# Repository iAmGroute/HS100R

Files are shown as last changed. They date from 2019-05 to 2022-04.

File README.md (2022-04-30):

# HS100R  
  
A custom pcb for the [TP-Link HS100 and HS110](https://www.tp-link.com/en/home-networking/smart-plug/hs110/) smart plugs.  
  
### Features:  
  
  - Uses the low power nRF51 SoC (+4dBm 2.4GHz) instead of a WiFi module.  
    Compatible with the popular nRF24 series modules.  
  
  - Maintains the features of the original HS100.  
  
  - Added sensors:  
  
Sensor      | MPN  
------------|-----  
Light       | LTR-30XALS  
Pressure    | DPS310  
Humidity    | SI7006-A20  
Temperature | SI7006-A20  
  
  - Adds low frequency front end for mains Voltage and Current sensing, wired to the ADC of the nRF51:  
    The idea is to function as a very basic oscilloscope.  
    Full bandwidth: 10 KHz  
      A gpio is wired to a low-pass filter at the input of the ADC, so that the bandwidth can be limited to around 1 KHz on demand.  
    Sampling frequency: around 40K samples/s (at 8 bits; around 20K samples/s at 10 bits)  
    For the current sensing side, a shunt resistor is required at the relay's board  
    (already installed on the HS110 - 1 mOhm, but will require cutting the board on the HS100 - 4 mOhm recommended)  
    Two low noise PGAs (MAX9939) are added in series to give a high dynamic range.  
    Max gain is limitted by the first PGA's noise at around 3000x (measures a few tens of mA with 4 mOhm shunt)  
  
  - The above can also be used to do Point-on-Wave switching:  
    Turn the relay on when the instantaneous voltage is near zero  
    and turn it off when the instantaneous current is near zero.  
    This is done to prevend arcing on the contacts of the relay and greately improve its life span  
    especially when switching heavy loads.  
  
### Prototype images and screenshots:  
  
#### Photos of the whole unit:
External photo 1 | External photo 2
-----------------|------------------
 | 
  
#### Custom PCB:
Top side | Bottom side
---------|-------------
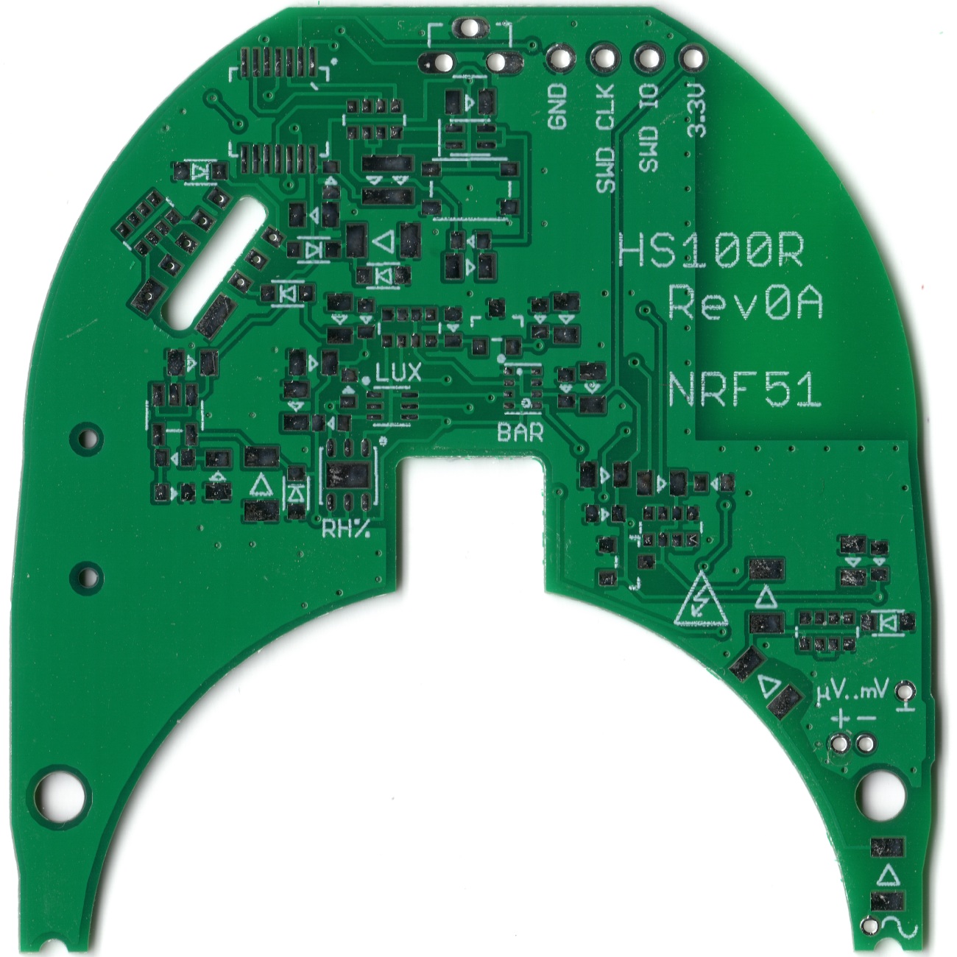
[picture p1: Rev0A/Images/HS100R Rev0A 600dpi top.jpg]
PCB top side
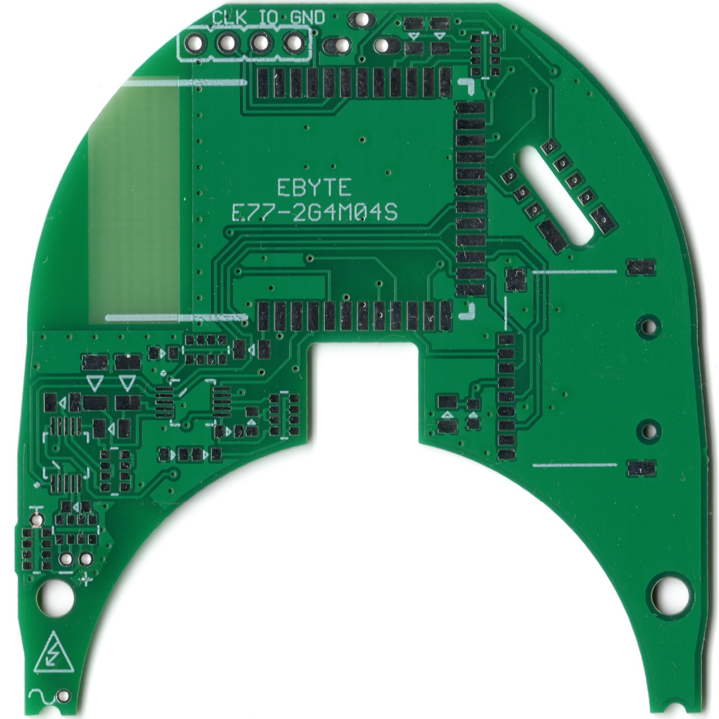
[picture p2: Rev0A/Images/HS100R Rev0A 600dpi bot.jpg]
PCB bottom side
 | 

#### Oscilloscope function screenshot ([Processing](https://en.wikipedia.org/wiki/Processing_(programming_language)) app):
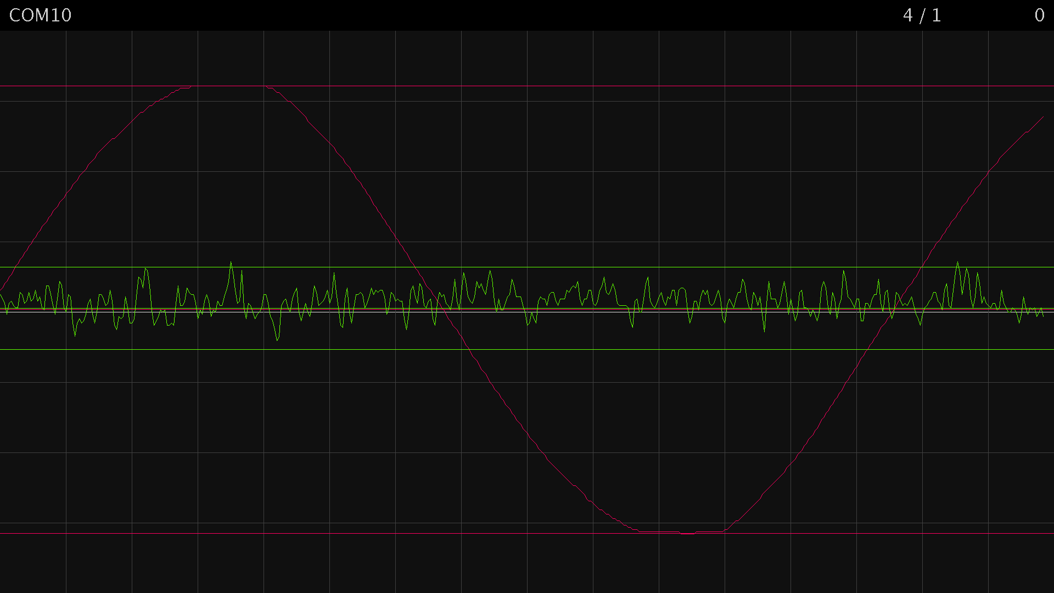
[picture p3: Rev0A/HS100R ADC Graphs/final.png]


### Note about revisions:  
  
Revisions that begin with 0 (e.g. Rev0B) are prototypes and only for reference and development.  
Unfortunately, TP-Link has discontinued these smart-plugs (at least in Europe), so development on this project has stopped.

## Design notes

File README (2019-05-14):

# HS100R

A custom pcb for the TP-Link HS100 and HS110 smart plugs.

### Features:

  - Uses the low power nRF51 SoC (+4dBm 2.4GHz) instead of a WiFi module.
    Compatible with the popular nRF24 series modules.

  - Maintains the features of the original HS100.

  - Added sensors:

Sensor      | MPN
------------|-----
Light       | LTR-30XALS
Pressure    | DPS310
Humidity    | SI7006-A20
Temperature | SI7006-A20

  - Adds low frequency front end for mains Voltage and Current sensing, wired to the ADC of the nRF51:
    The idea is to function as a very basic oscilloscope.
    Full bandwidth: 10 KHz
      A gpio is wired to a capacitor at the input of the ADC, so that the bandwidth can be limited to around 1 KHz on demand.
    Sampling frequency: around 40 KSps (at 8 bits, around half at 10 bits)
    For the current sensing side, a current shunt resistor is required at the relay's board
    (already installed on the HS110 - 1 mOhm, will require cutting the board on the HS100 - 4 mOhm recommended)
    Two low noise PGAs (MAX9939) are added in series to give a high dynamic range.
    Max gain limitted by the front PGA's noise at around 3000x (measures a few tens of mA with 4 mOhm shunt)

  - The above can also be used to do Point-on-Wave switching:
    Turn the relay on when the instantaneous voltage is near zero
    and turn it off when the instantaneous current is near zero.
    This is done to prevend arcing on the contacts of the relay and greately improve its life span
    especially when switching heavy loads.

### Prototype pictures and screenshots:

Comming soon !

### Note about revisions:

Revisions that begin with 0 (e.g. Rev0B) are prototypes and only for reference and development.
No fully working design is available yet.

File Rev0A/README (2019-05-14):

# HS100R Rev0A

Status: Finished (Archived)

## Known issues:

  - The pins of the pressure sensor (DPS310) are in the wrong order, so the sensor should not be mounted.
    [Datasheet, page 5](https://www.infineon.com/dgdl/Infineon-DPS310-DS-v01_00-EN.pdf?fileId=5546d462576f34750157750826c42242)
    (Note: the numbering is confusing, it starts from top right instead of top left)

  - The RF module's performance needs to be tested after being soldered on the pcb, and later placed in the case.
    It is possible that the FR4 below the antenna interferes.

  - It is not possible to fit the SD card without modifications to the case.

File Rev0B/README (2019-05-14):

# HS100R Rev0B

Status: Unfinished

TODO:

  - Remove SD card slot, or reposition it.

  - Fix the area of the DPS310. (maybe switch to a different IC ?)

  - Reevaluate the ground layer around the DPS310.

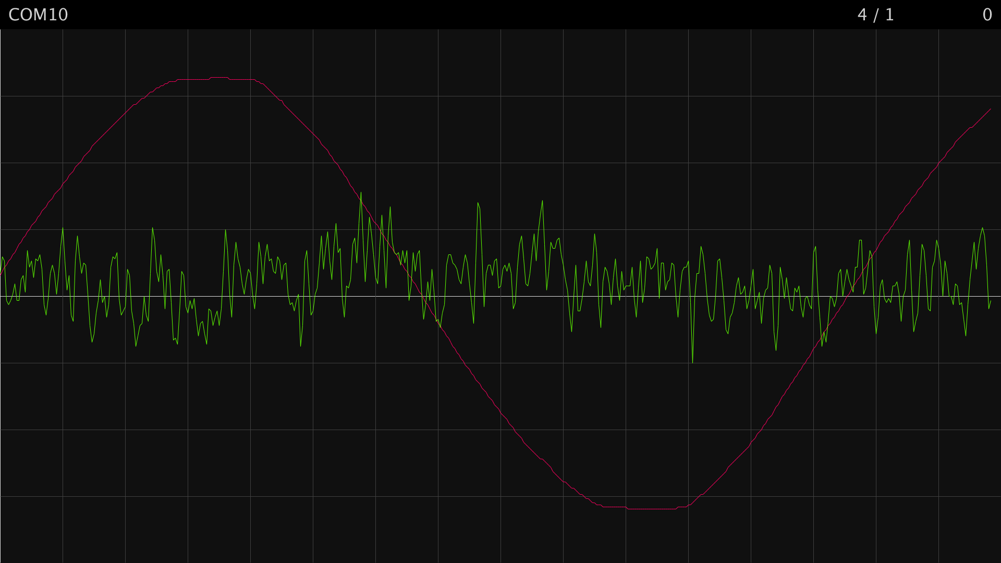
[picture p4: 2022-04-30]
Rev0A/HS100R ADC Graphs/no trim max gain 8 bit 1.png

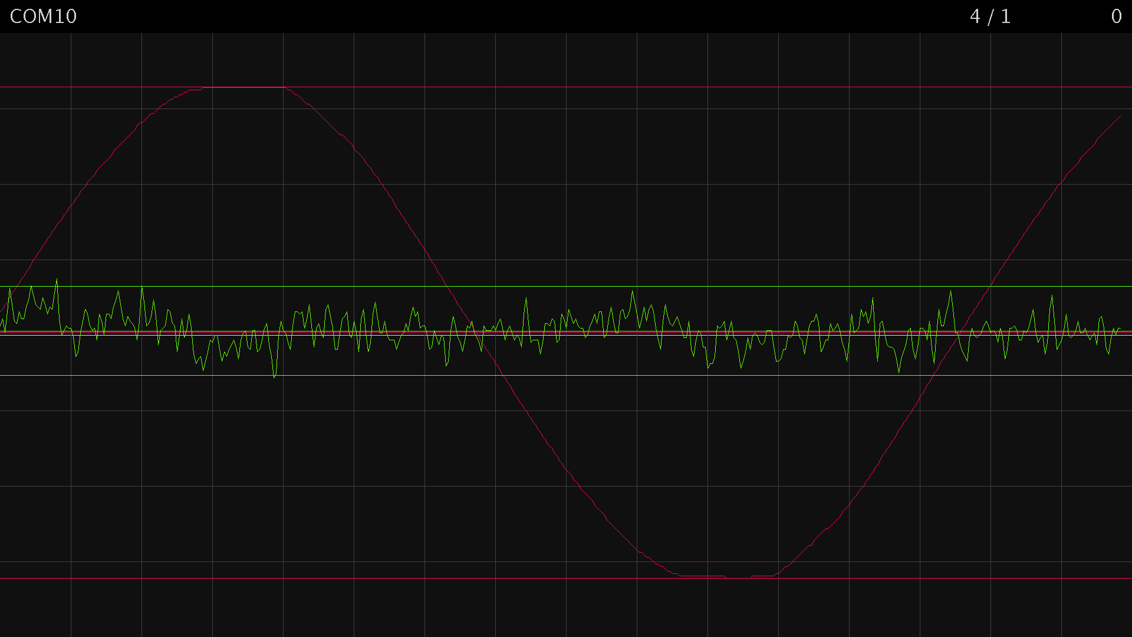
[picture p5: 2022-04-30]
Rev0A/HS100R ADC Graphs/cap and res.png

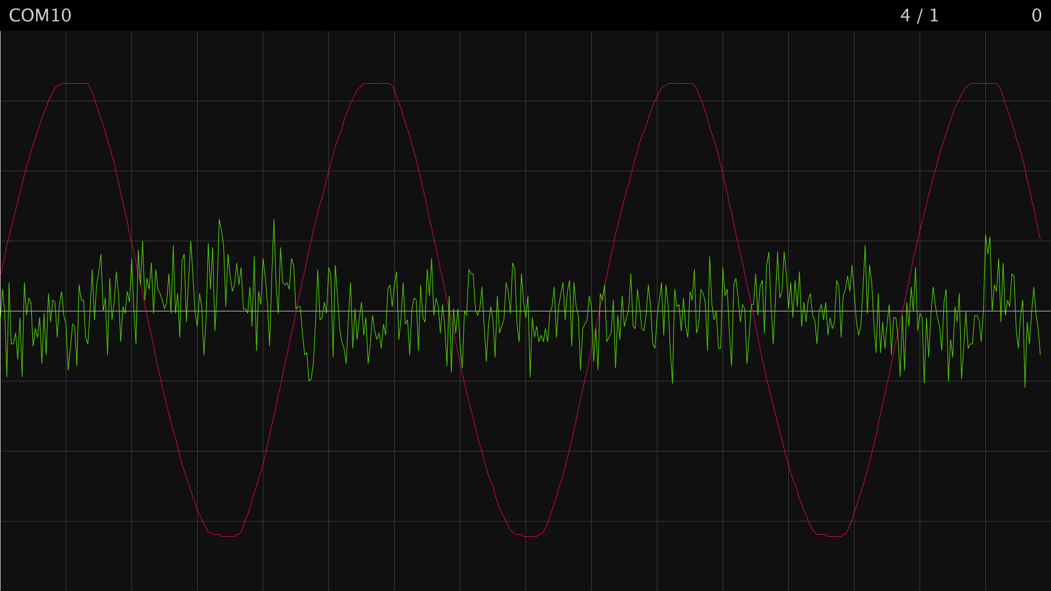
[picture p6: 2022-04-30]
Rev0A/HS100R ADC Graphs/no trim max gain 10 bit 2.png

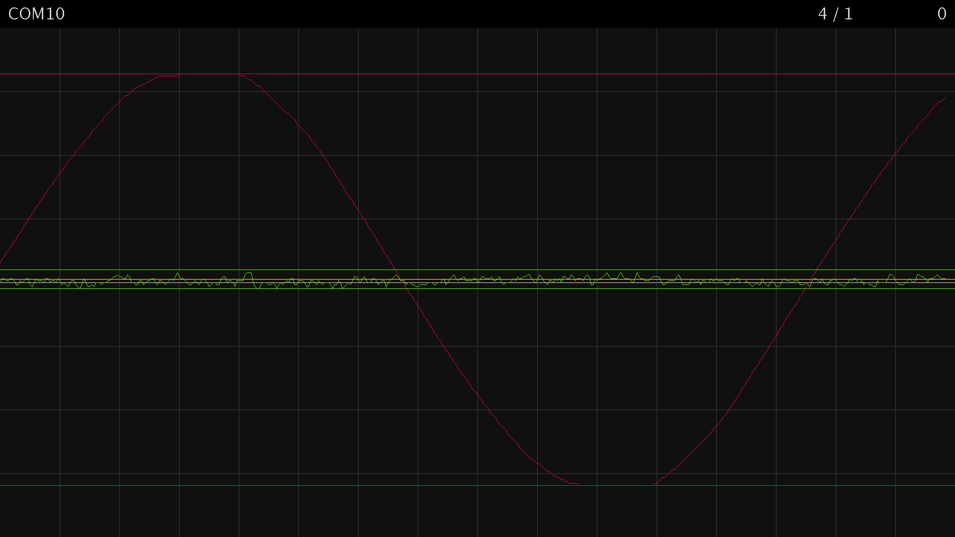
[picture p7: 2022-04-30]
Rev0A/HS100R ADC Graphs/cap no res 2.png

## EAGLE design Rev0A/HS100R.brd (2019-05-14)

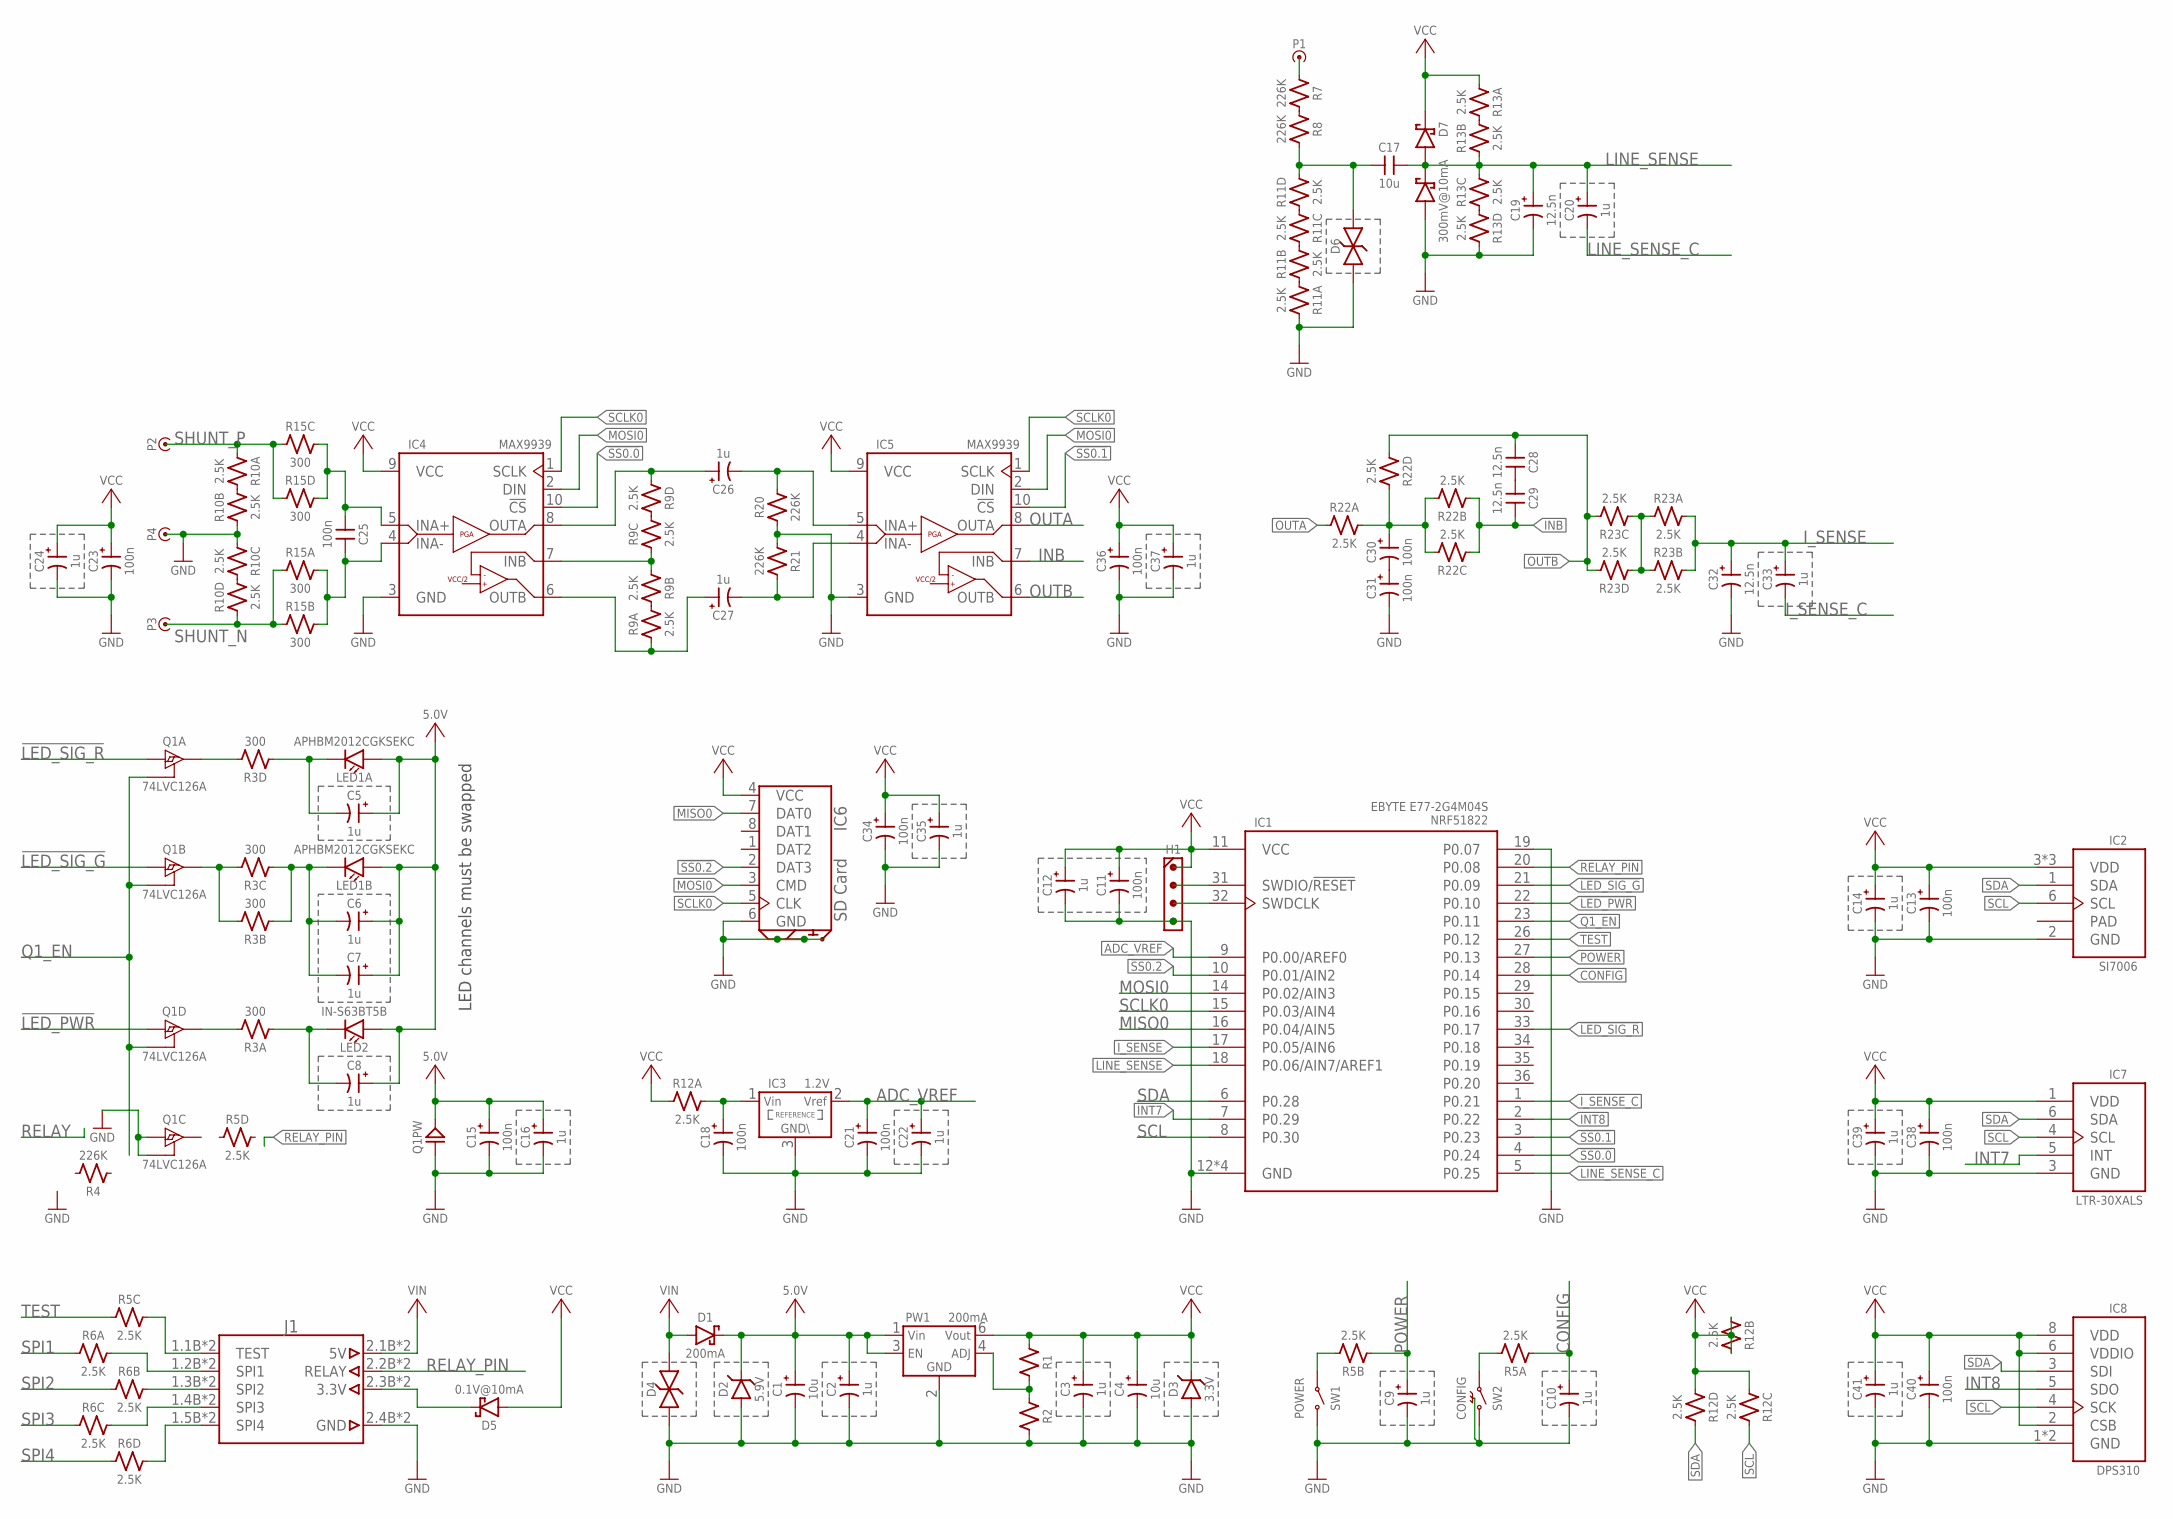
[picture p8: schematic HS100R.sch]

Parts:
C1, C4, C17: 10u; 1206
C2, C3, C5, C6, C7, C8, C9, C10, C12, C14, C16, C20, C22, C24, C26, C27, C33, C35, C37, C39, C41: 1u; 0805
C11, C13, C15, C18, C21, C23, C25, C30, C31, C34, C36, C38, C40: 100n; 0603
C19, C28, C29, C32: 12.5n; 0603
D1: 200mA; SOD-323F
D2: 5.9V; SOD-323F
D3: 3.3V; SOD-323F
D4, D6: DIODE_TVS_SOD-323F; SOD-323F
D5: 0.1V@10mA; SOD-323F
D7: 300mV@10mA; SOT-23
H1: HEADER_4X1-4X1; PIN_1_4X1
IC1: EBYTE_E77-2G4M04S
IC2: SI7006-A20; DFN-6_3.0_PAD
IC3: 1.2V; SOT-23
IC4, IC5: MAX9939_UMAX-10; UMAX-10
IC6: SD-CARD-MICRO-B; SD-MICRO-SPRINGED-B
IC7: LTR-30XALS
IC8: DPS310; LGA-8_2.0X2.5_0.65
J1: PCB_CONNECTOR
LED1: APHBM2012CGKSEKC; LED_DUAL-2.00X1.25
LED2: IN-S63BT5B; 0603
P1, P2, P3, P4: PIN-PIN_R_0.6; PIN_R_0.6_1X1
PW1: 200mA; SOT-23-5
Q1: 74LVC126A; SSOP-14_4.4
R1, R2: RESISTOR-0603; 0603
R3, R15: 300; 1206-QUAD
R4, R7, R8, R20, R21: 226K; 1206
R5, R6, R9, R10, R11, R12, R13, R22, R23: 2.5K; 1206-QUAD
SW1: POWER; GULLWING-4_4.2X3.2
SW2: CONFIG; SWITCH-RA_4.5X4.5

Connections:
5.0V: C1.C, C2.C, C5.C, C6.C, C7.C, C8.C, C15.C, C16.C, D1.C, D2.C, LED1.A1 (ANODE), LED1.A2 (ANODE), LED2.A (ANODE), PW1.1 (VIN), PW1.3 (EN), Q1.14 (VCC)
!LED_PWR: IC1.22 (P0.10), Q1.12 (IN)
!LED_SIG_G: IC1.21 (P0.09), Q1.5 (IN)
!LED_SIG_R: IC1.33 (P0.17), Q1.2 (IN)
!SS0.0: IC1.4 (P0.24), IC4.10 (!CS)
!SS0.1: IC1.3 (P0.23), IC5.10 (!CS)
!SS0.2: IC1.10 (P0.01/AIN2), IC6.2 (DAT3)
ADC_VREF: C21.C, C22.C, IC1.9 (P0.00/AREF0), IC3.2 (VOUT)
CONFIG: C10.C, IC1.28 (P0.14), R5.1
GND: C1.A (N), C2.A (N), C3.A (N), C4.A (N), C9.A (N), C10.A (N), C11.A (N), C12.A (N), C13.A (N), C14.A (N), C15.A (N), C16.A (N), C18.A (N), C19.A (N), C21.A (N), C22.A (N), C23.A (N), C24.A (N), C31.A (N), C32.A (N), C34.A (N), C35.A (N), C36.A (N), C37.A (N), C38.A (N), C39.A (N), C40.A (N), C41.A (N), D2.A, D3.A, D4.A (1), D6.A (1), D7.1 (A), H1.1.4, IC1.12 (GND), IC1.13 (GND), IC1.19 (P0.07), IC1.24 (GND), IC1.25 (GND), IC2.2 (GND), IC3.3 (GND), IC4.3 (GND), IC5.3 (GND), IC6.6 (GND), IC6.DETECT (DETECT1), IC6.SHIELD1 (SHIELD), IC6.SHIELD2 (SHIELD), IC6.SHIELD3 (SHIELD), IC6.SHIELD4 (DETECT2), IC7.3 (GND), IC8.1 (GND), IC8.7 (GND), J1.2.4B (GND), J1.2.4T (GND), P4.1.1, PW1.2 (GND), Q1.7 (GND), Q1.9 (IN), Q1.10 (OE), R2.C (2), R10.2 (1), R10.3 (1), R11.8 (2), R13.5 (2), R20.A (1), R21.A (1), SW1.3 (2), SW1.4 (2), SW2.2, SW2.SHIELD
INB: C29.C (2), IC5.7 (INB), R22.2 (1), R22.3 (1)
INT7: IC1.7 (P0.29), IC7.5 (INT)
INT8: IC1.2 (P0.22), IC8.5 (SDO)
I_SENSE: C32.C, C33.C, IC1.17 (P0.05/AIN6), R23.7 (2), R23.8 (2)
I_SENSE_C: C33.A (N), IC1.1 (P0.21)
LINE_SENSE: C17.C (2), C19.C, C20.C, D7.3 (COMMON), IC1.18 (P0.06/AIN7/AREF1), R13.2 (1), R13.6 (2)
LINE_SENSE_C: C20.A (N), IC1.5 (P0.25)
MISO0: IC1.16 (P0.04/AIN5), IC6.7 (DAT0)
MOSI0: IC1.14 (P0.02/AIN3), IC4.2 (DIN), IC5.2 (DIN), IC6.3 (CMD)
unnamed: D5.C, J1.2.3B (3.3V), J1.2.3T (3.3V)
unnamed: Q1.3 (OUT), R3.5 (2)
unnamed: PW1.4 (ADJ), R1.C (2), R2.A (1)
unnamed: C5.A (N), LED1.K1 (CATHODE), R3.4 (1)
unnamed: Q1.11 (OUT), R3.8 (2)
unnamed: Q1.6 (OUT), R3.6 (2), R3.7 (2)
unnamed: C8.A (N), LED2.C (CATHODE), R3.1
unnamed: J1.1.2B (SPI1), J1.1.2T (SPI1), R6.8 (2)
unnamed: C6.A (N), C7.A (N), LED1.K2 (CATHODE), R3.2 (1), R3.3 (1)
unnamed: R5.7 (2), SW1.1, SW1.2 (1)
unnamed: R11.3 (1), R11.4 (1)
unnamed: R5.8 (2), SW2.1
unnamed: J1.1.1B (TEST), J1.1.1T (TEST), R5.6 (2)
unnamed: J1.1.3B (SPI2), J1.1.3T (SPI2), R6.7 (2)
unnamed: J1.1.4B (SPI3), J1.1.4T (SPI3), R6.6 (2)
unnamed: J1.1.5B (SPI4), J1.1.5T (SPI4), R6.5 (2)
unnamed: P1.1.1, R7.A (1)
unnamed: R7.C (2), R8.A (1)
unnamed: H1.1.3, IC1.32 (SWDCLK)
unnamed: H1.1.2, IC1.31 (SWDIO/!RESET)
unnamed: C17.A (1), D6.C (2), R8.C (2), R11.5 (2)
unnamed: C18.C, IC3.1 (VIN), R12.8 (2)
unnamed: R13.7 (2), R13.8 (2)
unnamed: R13.3 (1), R13.4 (1)
unnamed: C25.A (1), IC4.5 (INA+), R15.5 (2), R15.6 (2)
unnamed: C25.C (2), IC4.4 (INA-), R15.7 (2), R15.8 (2)
unnamed: IC4.7 (INB), R9.2 (1), R9.3 (1)
unnamed: C28.C (2), C29.A (1)
unnamed: R11.6 (2), R11.7 (2)
unnamed: C30.C, R22.5 (2), R22.6 (2), R22.7 (2), R22.8 (2)
unnamed: C26.A (N), IC5.5 (INA+), R20.C (2)
unnamed: R23.1, R23.2 (1), R23.3 (1), R23.4 (1)
unnamed: C27.A (N), IC5.4 (INA-), R21.C (2)
unnamed: C26.C, IC4.8 (OUTA), R9.4 (1)
unnamed: R9.5 (2), R9.6 (2)
unnamed: C30.A (N), C31.C
unnamed: R9.7 (2), R9.8 (2)
unnamed: C27.C, IC4.6 (OUTB), R9.1
unnamed: R10.5 (2), R10.6 (2)
unnamed: R10.7 (2), R10.8 (2)
unnamed: R11.1, R11.2 (1)
OUTA: IC5.8 (OUTA), R22.1
OUTB: C28.A (1), IC5.6 (OUTB), R22.4 (1), R23.5 (2), R23.6 (2)
POWER: C9.C, IC1.27 (P0.13), R5.2 (1)
Q1_EN: IC1.23 (P0.11), Q1.1 (OE), Q1.4 (OE), Q1.13 (OE)
RELAY_PIN: IC1.20 (P0.08), J1.2.2B (RELAY), J1.2.2T (RELAY)
SCL: IC1.8 (P0.30), IC2.6 (SCL), IC7.4 (SCL), IC8.4 (SCK), R12.6 (2)
SCLK0: IC1.15 (P0.03/AIN4), IC4.1 (SCLK), IC5.1 (SCLK), IC6.5 (CLK)
SDA: IC1.6 (P0.28), IC2.1 (SDA), IC7.6 (SDA), IC8.3 (SDI), R12.5 (2)
SHUNT_N: P3.1.1, R10.4 (1), R15.1, R15.2 (1)
SHUNT_P: P2.1.1, R10.1, R15.3 (1), R15.4 (1)
SPI1: R6.1
SPI2: R6.2 (1)
SPI3: R6.3 (1)
SPI4: R6.4 (1)
TEST: IC1.26 (P0.12), R5.3 (1)
VCC: C3.C, C4.C, C11.C, C12.C, C13.C, C14.C, C23.C, C24.C, C34.C, C35.C, C36.C, C37.C, C38.C, C39.C, C40.C, C41.C, D3.C, D5.A, D7.2 (C), H1.1.1, IC1.11 (VCC), IC2.3 (VDD), IC2.4 (VDD), IC2.5 (VDD), IC4.9 (VCC), IC5.9 (VCC), IC6.4 (VCC), IC7.1 (VDD), IC8.2 (CSB), IC8.6 (VDDIO), IC8.8 (VDD), PW1.6 (VOUT), R1.A (1), R12.1, R12.2 (1), R12.3 (1), R12.4 (1), R12.7 (2), R13.1
VIN: D1.A, D4.C (2), J1.2.1B (5V), J1.2.1T (5V)

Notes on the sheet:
LED channels must be swapped

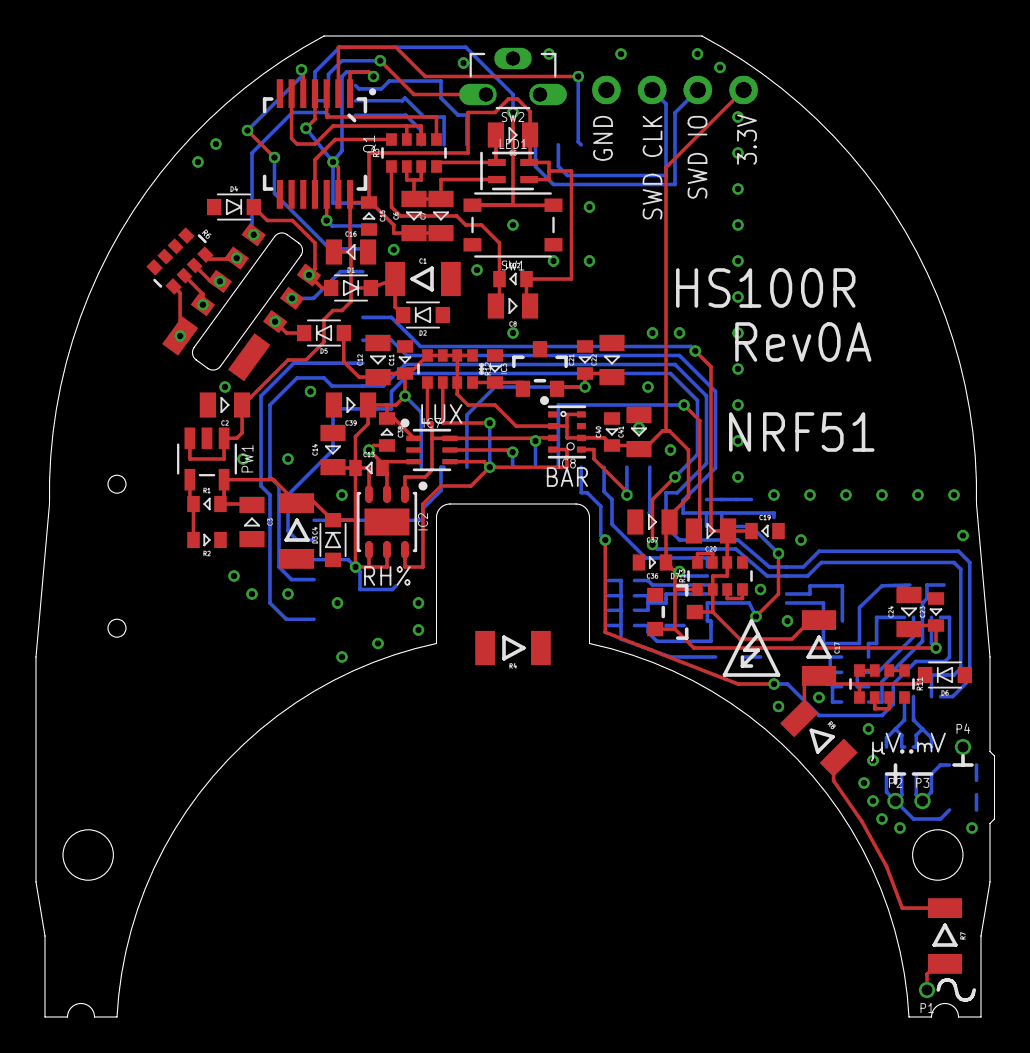
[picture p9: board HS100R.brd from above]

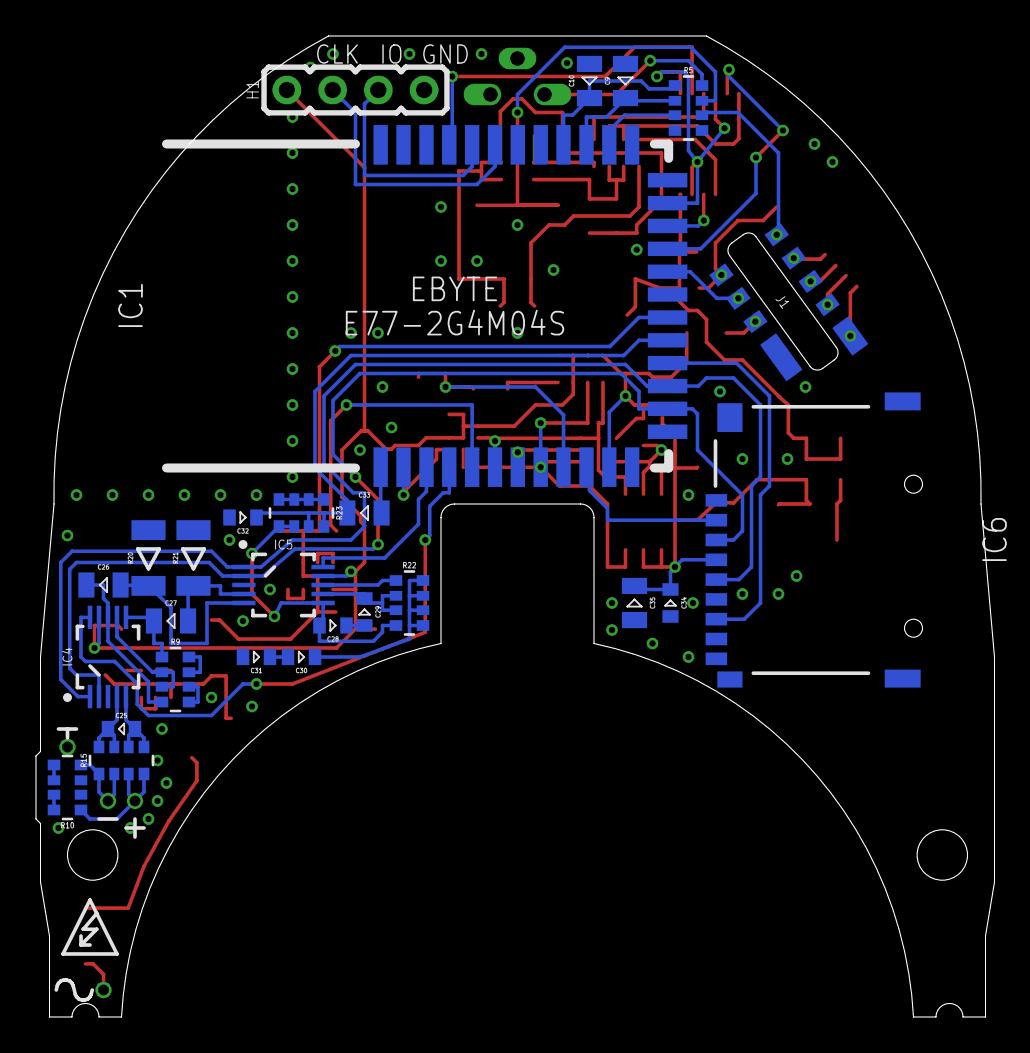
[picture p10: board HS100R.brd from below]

Board: 2 copper layers, 53.2 x 54.5 mm, 86 parts (27 on the bottom side), 73 nets.

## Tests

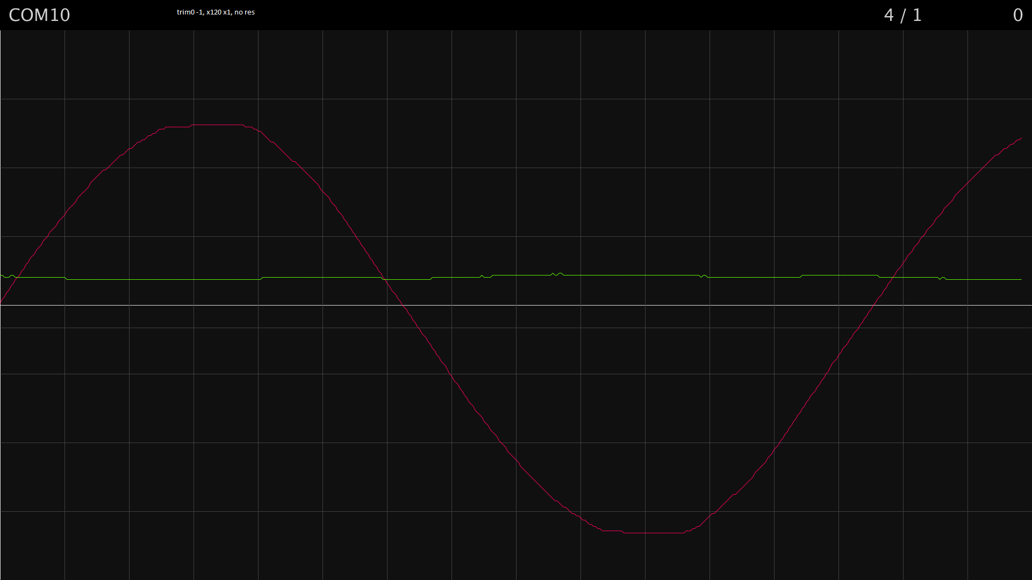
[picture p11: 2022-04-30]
Rev0A/HS100R ADC Graphs/test3.png

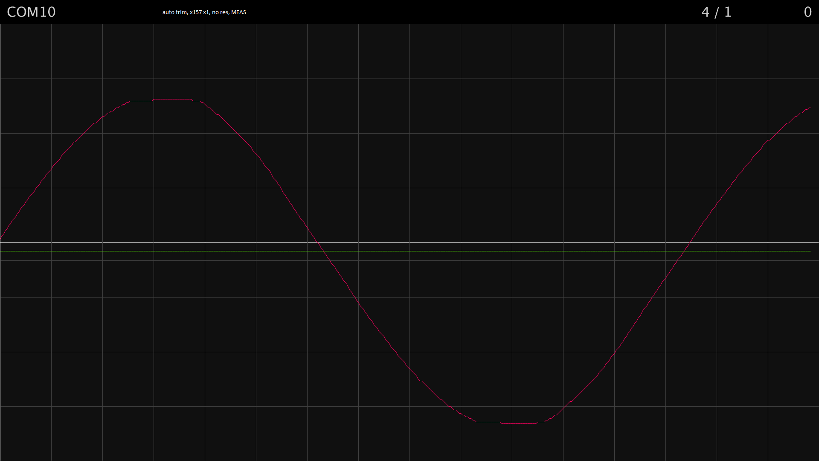
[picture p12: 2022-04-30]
Rev0A/HS100R ADC Graphs/test6.png
